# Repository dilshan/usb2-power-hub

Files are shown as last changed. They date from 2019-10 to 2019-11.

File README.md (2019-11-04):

4 Port high power USB hub 
=========================

   
  
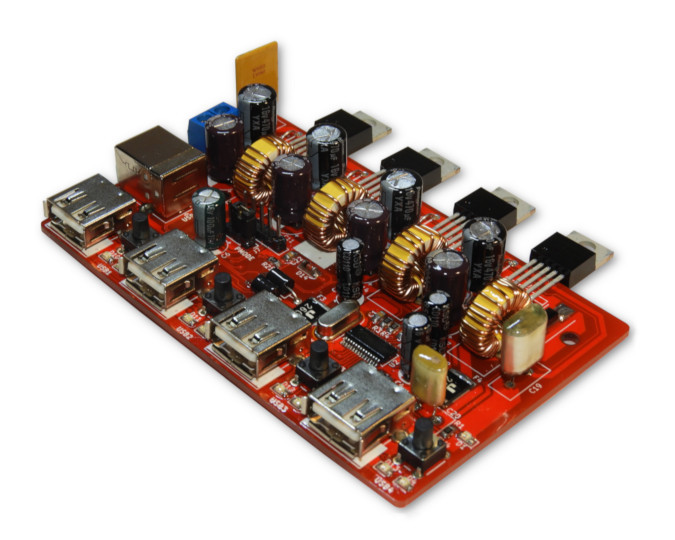
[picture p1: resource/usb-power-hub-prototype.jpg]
Prototype version of USB hub


This project is about a high current USB 2.0 hub that is specifically designed to drive USB powered development boards and experimental peripherals.

The core element of this USB hub is the *FE1.1s* USB 2.0 hub controller. The *FE1.1s* is a low cost, 4-port, high-speed USB hub controller you should be able to find on *eBay* or AliExpress.

This USB hub adds the following additional features to those offered by the *FE1.1s*:

 - Switches to on/off and reset individual USB ports.
 - Capability to provide a maximum of 3A of current from each USB port.
 - Power using 9V to 15V DC voltage source.

This USB hub uses a *PIC16F630* MCU and four *LM2596-5.0* switching regulators. 

[You can find everything about how to build and use this project on our wiki.](https://github.com/dilshan/usb2-power-hub/wiki)

Licenses
--------

This is a [certified open hardware project](https://certification.oshwa.org/lk000005.html) and all its design files, firmware source code, documentation, and other resource files are available at this project source repository. The content of this project is distributed under the terms of the following licenses:

 - Hardware License: [CC BY 4.0](https://creativecommons.org/licenses/by/4.0/)
 - Software License: [MIT](https://github.com/dilshan/usb-morse-keyer/blob/master/LICENSE)
 - Documentation License: [CC BY 4.0](https://creativecommons.org/licenses/by/4.0/)

OSHW-LK000005 (https://certification.oshwa.org/lk000005.html)

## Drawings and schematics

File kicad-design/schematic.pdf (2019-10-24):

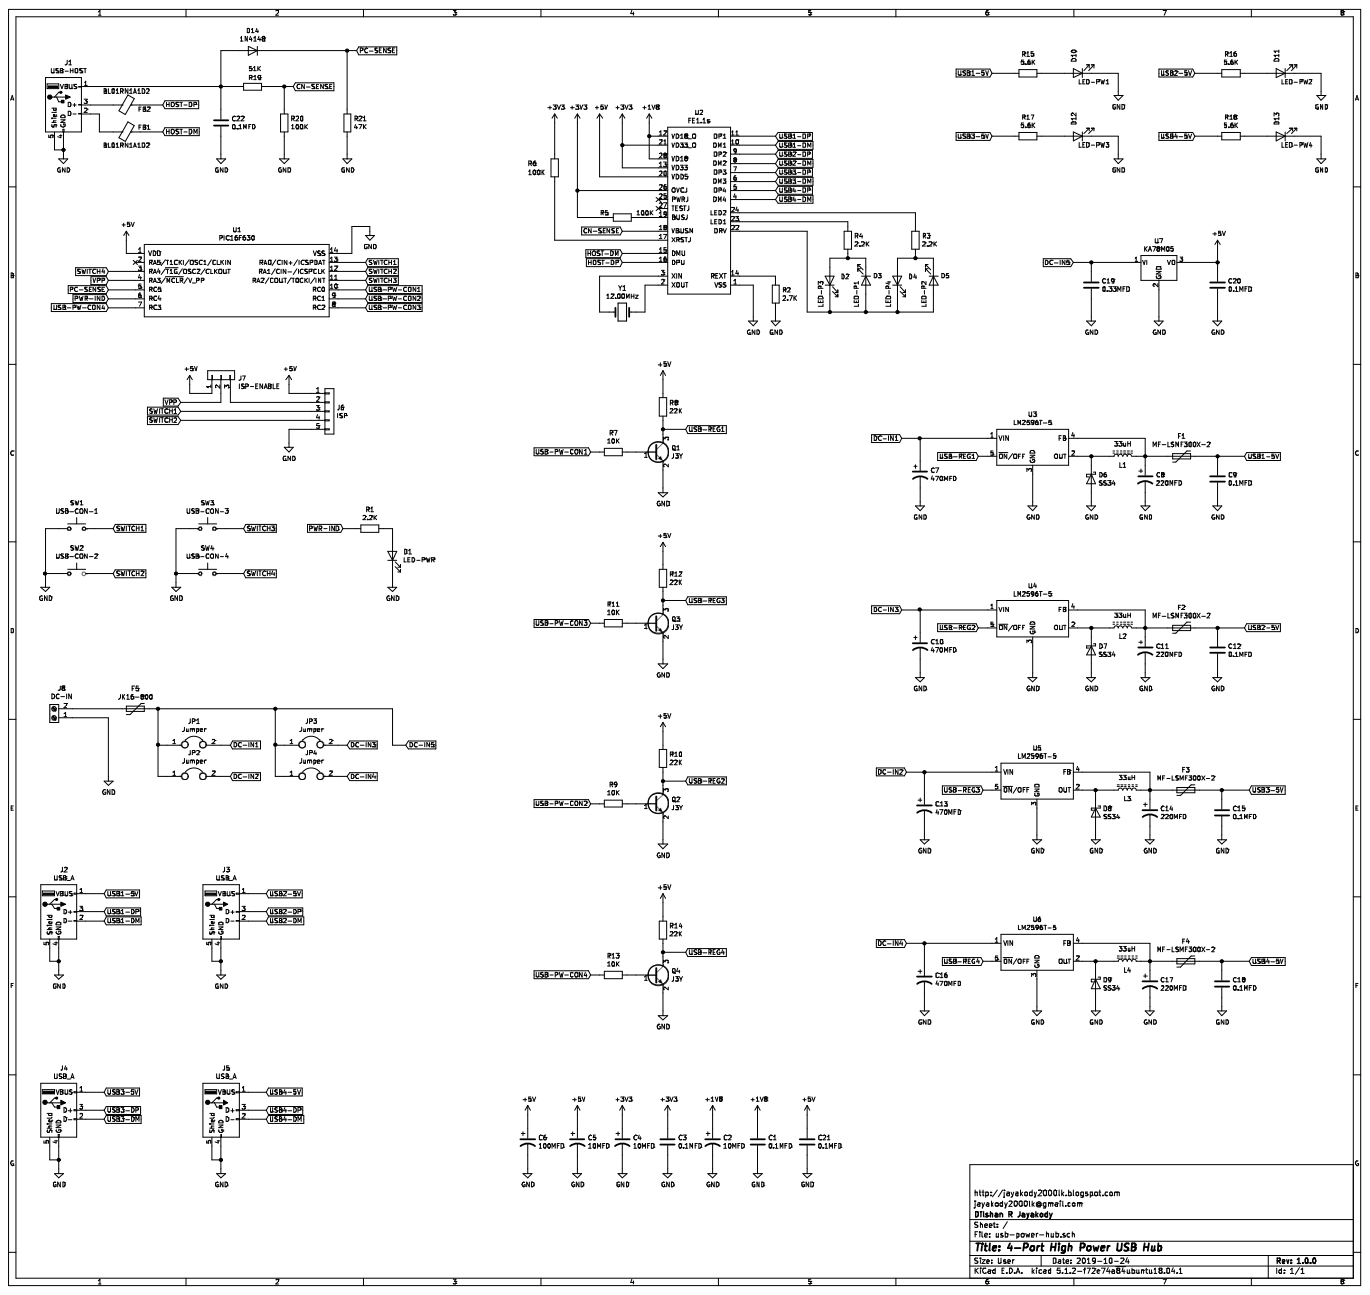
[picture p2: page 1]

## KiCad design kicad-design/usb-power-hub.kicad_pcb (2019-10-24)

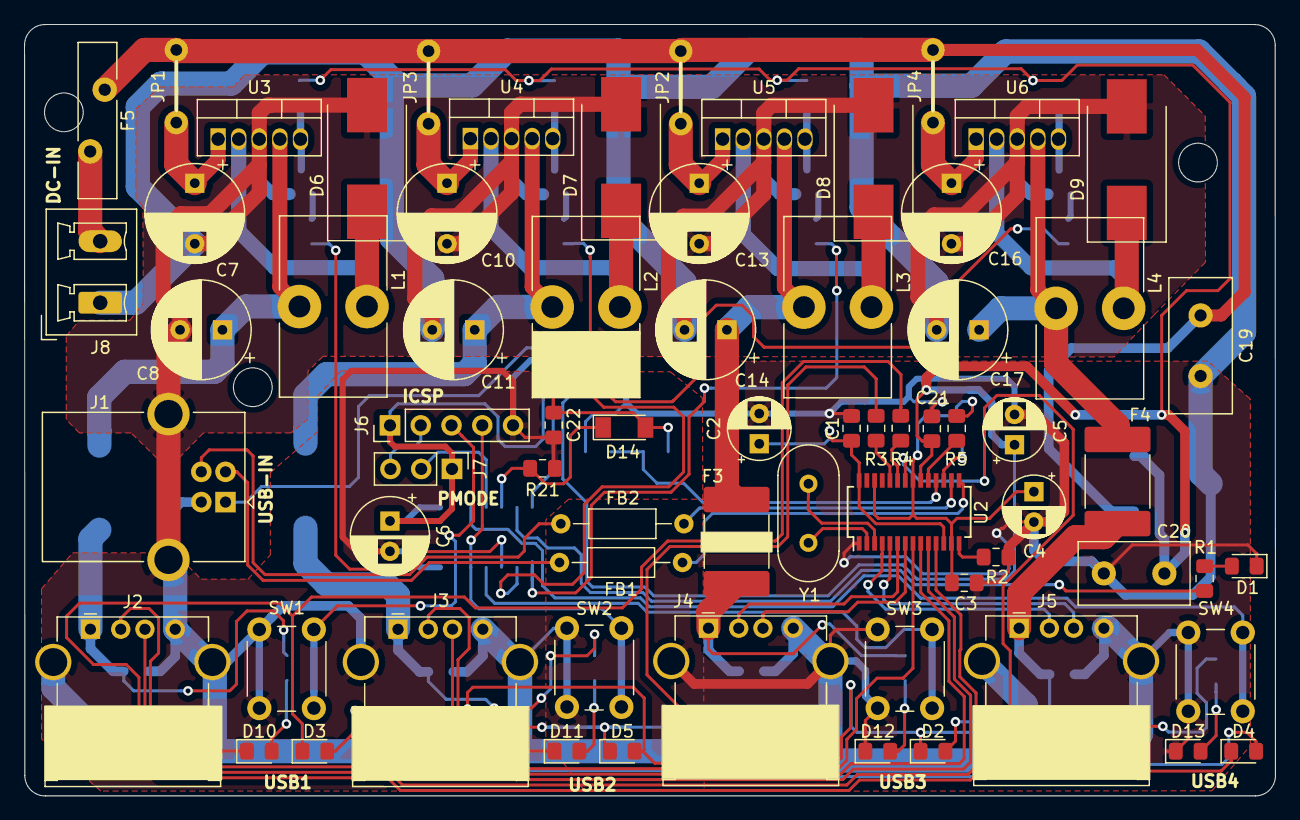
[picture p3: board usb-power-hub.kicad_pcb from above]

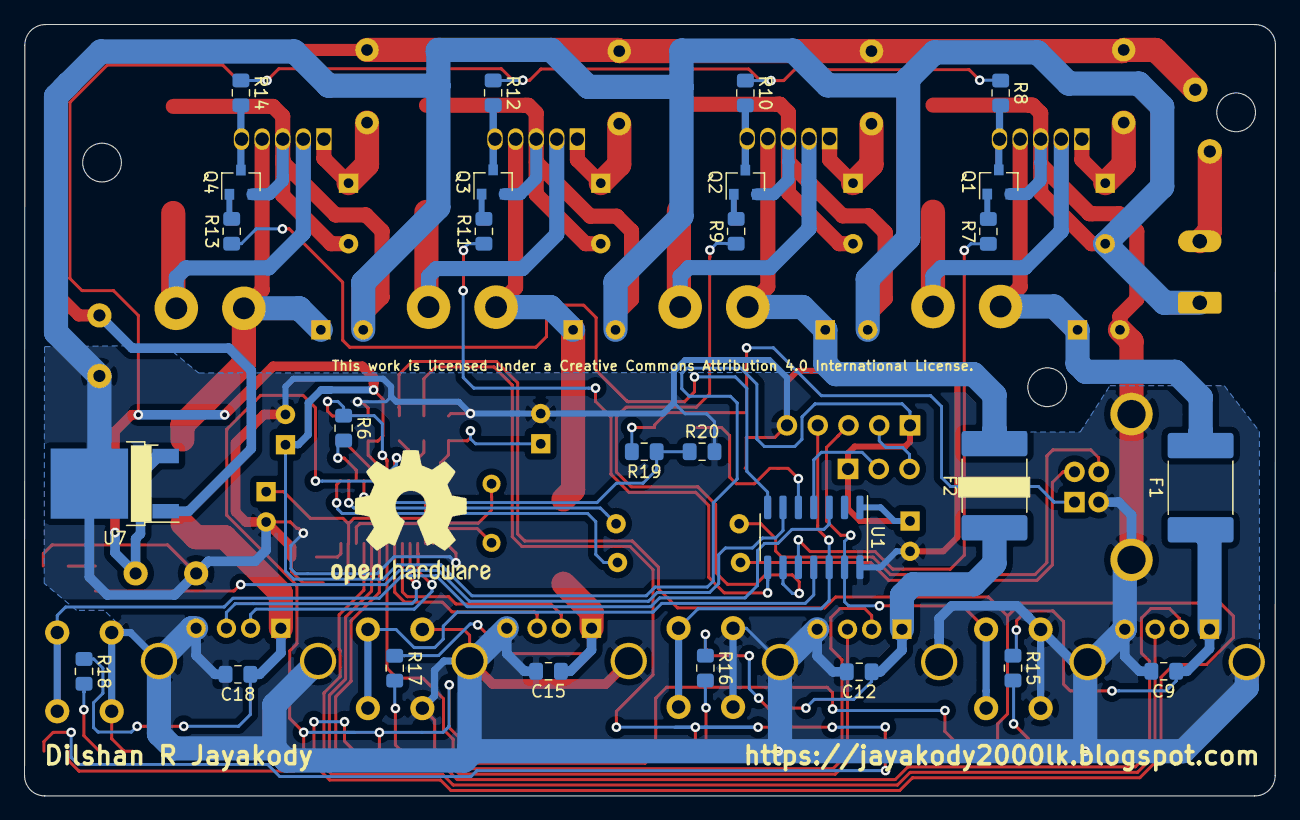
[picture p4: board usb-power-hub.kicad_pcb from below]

Board: 2 copper layers, 103.3 x 63.7 mm, 99 parts (27 on the bottom side), 71 nets.

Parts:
 : MountingHole_3.2mm_M3_ISO14580
 #2,  #3: MountingHole_3.2mm_M3_ISO14580
C1, C3, C9, C12, C15, C18, C21, C22: 0.1MFD; C_0805_2012Metric_Pad1.15x1.40mm_HandSolder
C2, C4, C5: 10MFD; CP_Radial_D5.0mm_P2.50mm
C6: 100MFD; CP_Radial_D6.3mm_P2.50mm
C7, C10, C13, C16: 470MFD; CP_Radial_D8.0mm_P5.00mm
C8, C11, C14, C17: 220MFD; CP_Radial_D8.0mm_P3.50mm
C19: 0.33MFD; C_Disc_D11.0mm_W5.0mm_P5.00mm
C20: 0.1MFD; C_Disc_D9.0mm_W5.0mm_P5.00mm
D1: LED-PWR; LED_0805_2012Metric_Pad1.15x1.40mm_HandSolder
D2: LED-P3; LED_0805_2012Metric_Pad1.15x1.40mm_HandSolder
D3: LED-P1; LED_0805_2012Metric_Pad1.15x1.40mm_HandSolder
D4: LED-P4; LED_0805_2012Metric_Pad1.15x1.40mm_HandSolder
D5: LED-P2; LED_0805_2012Metric_Pad1.15x1.40mm_HandSolder
D6, D7, D8, D9: SS34; D_SMC_Handsoldering
D10: LED-PW1; LED_0805_2012Metric_Pad1.15x1.40mm_HandSolder
D11: LED-PW2; LED_0805_2012Metric_Pad1.15x1.40mm_HandSolder
D12: LED-PW3; LED_0805_2012Metric_Pad1.15x1.40mm_HandSolder
D13: LED-PW4; LED_0805_2012Metric_Pad1.15x1.40mm_HandSolder
D14: 1N4148; D_MiniMELF
F1, F2, F3, F4: MF-LSMF300X-2; Fuse_2920_7451Metric_Pad2.10x5.45mm_HandSolder
F5: JK16-800; Fuse_Bourns_MF-RG800
FB1, FB2: BL01RN1A1D2; L_Axial_L5.3mm_D2.2mm_P10.16mm_Horizontal_Vishay_IM-1
J1: USB-HOST; USB_B_OST_USB-B1HSxx_Horizontal
J2, J3, J4, J5: USB_A; USB_A_Stewart_SS-52100-001_Horizontal
J6: ISP; PinHeader_1x05_P2.54mm_Vertical
J7: ISP-ENABLE; PinHeader_1x03_P2.54mm_Vertical
J8: DC-IN; PhoenixContact_MCV_1,5_2-G-5.08_1x02_P5.08mm_Vertical
JP1, JP2, JP3, JP4: Jumper; WireJumper
L1, L2, L3, L4: 33uH; L_Toroid_Vertical_L14.7mm_W8.6mm_P5.58mm_Pulse_KM-1
Q1, Q2, Q3, Q4: J3Y; SOT-23
R1, R3, R4: 2.2K; R_0805_2012Metric_Pad1.15x1.40mm_HandSolder
R2: 2.7K; R_0805_2012Metric_Pad1.15x1.40mm_HandSolder
R5, R6, R20: 100K; R_0805_2012Metric_Pad1.15x1.40mm_HandSolder
R7, R9, R11, R13: 10K; R_0805_2012Metric_Pad1.15x1.40mm_HandSolder
R8, R10, R12, R14: 22K; R_0805_2012Metric_Pad1.15x1.40mm_HandSolder
R15, R16, R17, R18: 5.6K; R_0805_2012Metric_Pad1.15x1.40mm_HandSolder
R19: 51K; R_0805_2012Metric_Pad1.15x1.40mm_HandSolder
R21: 47K; R_0805_2012Metric_Pad1.15x1.40mm_HandSolder
SW1: USB-CON-1; SW_PUSH_6mm
SW2: USB-CON-2; SW_PUSH_6mm
SW3: USB-CON-3; SW_PUSH_6mm
SW4: USB-CON-4; SW_PUSH_6mm
U1: PIC16F630; SOIC-14_3.9x8.7mm_P1.27mm
U2: FE1.1s; SSOP-28_3.9x9.9mm_P0.635mm
U3, U4, U5, U6: LM2596T-5; TO-220-5_Vertical
U7: KA78M05; TO-252-2
Y1: 12.00MHz; Crystal_HC49-U_Vertical

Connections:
+1V8: C1.1, C2.1, U2.12, U2.28
+3V3: C3.1, C4.1, R5.2, R6.1, U2.13, U2.21, U2.26
+5V: C5.1, C6.1, C20.1, C21.1, J6.1, J7.1, R8.1, R10.1, R12.1, R14.1, U1.1, U2.20, U7.3
CN-SENSE: R19.1, R20.1, U2.18
DC-IN1: C7.1, JP1.2, U3.1
DC-IN2: C13.1, JP2.2, U5.1
DC-IN3: C10.1, JP3.2, U4.1
DC-IN4: C16.1, JP4.2, U6.1
DC-IN5: C19.1, F5.1, JP1.1, JP2.1, JP3.1, JP4.1, U7.1
GND: C1.2, C2.2, C3.2, C4.2, C5.2, C6.2, C7.2, C8.2, C9.2, C10.2, C11.2, C12.2, C13.2, C14.2, C15.2, C16.2, C17.2, C18.2, C19.2, C20.2, C21.2, C22.2, D1.1, D6.2, D7.2, D8.2, D9.2, D10.1, D11.1, D12.1, D13.1, J1.4, J1.5, J2.4, J2.5, J3.4, J3.5, J4.4, J4.5, J5.4, J5.5, J6.5, J8.1, Q1.2, Q2.2, Q3.2, Q4.2, R2.2, R20.2, R21.2, SW1.1, SW2.1, SW3.1, SW4.1, U1.14, U2.1, U3.3, U4.3, U5.3, U6.3, U7.2
HOST-DM: FB1.1, U2.15
HOST-DP: FB2.1, U2.16
unnamed: C8.1, F1.2, L1.2, U3.4
unnamed: C11.1, F2.2, L2.2, U4.4
unnamed: C14.1, F3.2, L3.2, U5.4
unnamed: C17.1, F4.2, L4.2, U6.4
unnamed: C22.1, D14.2, J1.1, R19.2
unnamed: D1.2, R1.2
unnamed: D2.1, D3.2, D4.1, D5.2, U2.22
unnamed: D2.2, D3.1, R4.2
unnamed: D4.2, D5.1, R3.2
unnamed: D6.1, L1.1, U3.2
unnamed: D7.1, L2.1, U4.2
unnamed: D8.1, L3.1, U5.2
unnamed: D9.1, L4.1, U6.2
unnamed: D10.2, R15.2
unnamed: D11.2, R16.2
unnamed: D12.2, R17.2
unnamed: D13.2, R18.2
unnamed: F5.2, J8.2
unnamed: FB1.2, J1.2
unnamed: FB2.2, J1.3
unnamed: J6.2, J7.3
unnamed: Q1.1, R7.2
unnamed: Q2.1, R9.2
unnamed: Q3.1, R11.2
unnamed: Q4.1, R13.2
unnamed: R2.1, U2.14
unnamed: R3.1, U2.24
unnamed: R4.1, U2.23
unnamed: R5.1, U2.19
unnamed: R6.2, U2.17
unnamed: U2.2, Y1.2
unnamed: U2.3, Y1.1
PC-SENSE: D14.1, R21.1, U1.5
PWR-IND: R1.1, U1.6
SWITCH1: J6.3, SW1.2, U1.13
SWITCH2: J6.4, SW2.2, U1.12
SWITCH3: SW3.2, U1.11
SWITCH4: SW4.2, U1.3
USB1-5V: C9.1, F1.1, J2.1, R15.1
USB1-DM: J2.2, U2.10
USB1-DP: J2.3, U2.11
USB2-5V: C12.1, F2.1, J3.1, R16.1
USB2-DM: J3.2, U2.8
USB2-DP: J3.3, U2.9
USB3-5V: C15.1, F3.1, J4.1, R17.1
USB3-DM: J4.2, U2.6
USB3-DP: J4.3, U2.7
USB4-5V: C18.1, F4.1, J5.1, R18.1
USB4-DM: J5.2, U2.4
USB4-DP: J5.3, U2.5
USB-PW-CON1: R7.1, U1.10
USB-PW-CON2: R9.1, U1.9
USB-PW-CON3: R11.1, U1.8
USB-PW-CON4: R13.1, U1.7
USB-REG1: Q1.3, R8.2, U3.5
USB-REG2: Q2.3, R10.2, U4.5
USB-REG3: Q3.3, R12.2, U5.5
USB-REG4: Q4.3, R14.2, U6.5
VPP: J7.2, U1.4

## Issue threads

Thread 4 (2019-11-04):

Standalone USB Device Charger feature?

rayrrr, 2019-11-04:
Thanks for the cool project! Can this device also act as a standalone USB Device Charger when powered via 12-20V but not connected to a host computer via USB?

In other words, can I charge my phone with it?

If so, let's document that in the Usage Instructions in the wiki.

dilshan, 2019-11-05:
@rayrrr With current firmware this hub need to connect with host computer to activate it's 4 ports. If you are interested to use this as a USB device charger you need to modify "_USB sense_" section of the firmware.

As you suggested I'll add this feature request to my next firmware update.

dgags, 2021-09-11:
To turn this into a charging only device, it looks like you can change line 35 in "usb2-power-hub/firmware/main.c"
from:  usbFlag = PORTC & 0x20;
to:       usbFlag = 0x20;

If I have this right, it should basically just say that the USB host is always connected without bothering to really look if it connected to a computer. I admit that this does not elegantly solve the problem in a way that allows you to selectively turn this feature on and off. I would expect a hardwired switch that the PIC could query is one such way.

I hope this helps anyone wanting to turn this into a high current multi-port usb charging device.

dilshan, 2021-09-12:
@dgags good suggestion!
Yes, assigning `0x20` to the `usbFlag`, disable the USB sense feature from the firmware. I did not include this in firmware because this may change the scope of the project (from USB hub to USB charger).

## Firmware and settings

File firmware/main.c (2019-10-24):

//***********************************************************************************
// Copyright (c) 2019 Dilshan R Jayakody. [jayakody2000lk@gmail.com]
//
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
#include <xc.h>

#include "main.h"

int main() 
{
    unsigned char idleCounter = 0;
    unsigned char idleFlag = 0;
    
    initSystem();
    
    while(1)
    {
        usbFlag = PORTC & 0x20;
                
        if(usbFlag == 0x20)
        {
            // USB host connection is triggered and start to verify the connection.

            PORTC = 0x00;
            __delay_ms(500);
            usbFlag = PORTC & 0x20;
            
            if(usbFlag == 0x20)
            {
                // USB host connection is available and turn on the USB HUB.

                switchConfig = eeprom_read(0x00);
                liveServiceRoutine();
                
                // Host USB line is disconnected. Shutting down all USB ports.
                idleCounter = 0;
                idleFlag = 0;
                PORTC = 0x00;
            }
        }
        else 
        {
            // Blink power indicator in USB disconnected mode. 
            if((++idleCounter) == 10)
            {
                idleFlag = ~idleFlag;
                
                if(idleFlag == 0)
                {
                    PORTC = 0x00;
                    idleCounter = 0;
                }
                else
                {
                    PORTC = 0x10;
                    idleCounter = 8;
                }
            }
        }
        
        __delay_ms(100);
    }
}

void toggleStateBit(unsigned char togglePos, unsigned char *globalConfig, unsigned char *localConfig)
{
    if(((*globalConfig) & togglePos) == 0x00)
    {
        // Activate the specified bit.
        (*globalConfig) |= togglePos;
        (*localConfig) |= togglePos;
    }
    else
    {
        // Clear the specified bit.
        (*globalConfig) &= (~togglePos);
        (*localConfig) &= (~togglePos);
    }
}

void liveServiceRoutine()
{
    unsigned char buttonState = PORTA;
    unsigned char lastButtonState = buttonState;
    
    unsigned char resetState[4] = {0x00, 0x00, 0x00, 0x00};
    unsigned char buttonDownCounter[4] = {0x00, 0x00, 0x00, 0x00};
    
    // Restore USB ports to last state.
    switchConfig |= 0x10;
    unsigned char memSwitchConfig = switchConfig;
    
    while(usbFlag == 0x20)
    {
        PORTC = switchConfig;

        // Initiate reset cycle for USB port #1.  
        if(BUTTON_PRESSED(BUTTON_1) && ((memSwitchConfig & USB_PORT_1) == USB_PORT_1))
        {
            resetState[0] = RESET_LIMIT;
            switchConfig &= (~USB_PORT_1);
            buttonDownCounter[0] = 0;
        }
        
        // Initiate reset cycle for USB port #2.
        if(BUTTON_PRESSED(BUTTON_2) && ((memSwitchConfig & USB_PORT_2) == USB_PORT_2))
        {
            resetState[1] = RESET_LIMIT;
            switchConfig &= (~USB_PORT_2);
            buttonDownCounter[1] = 0;
        }
        
        // Initiate reset cycle for USB port #3.
        if(BUTTON_PRESSED(BUTTON_3) && ((memSwitchConfig & USB_PORT_3) == USB_PORT_3))
        {
            resetState[2] = RESET_LIMIT;
            switchConfig &= (~USB_PORT_3);
            buttonDownCounter[2] = 0;
        }
        
        // Initiate reset cycle for USB port #4.
        if(BUTTON_PRESSED(BUTTON_4) && ((memSwitchConfig & USB_PORT_4) == USB_PORT_4))    
        {
            resetState[3] = RESET_LIMIT;
            switchConfig &= (~USB_PORT_4);
            buttonDownCounter[3] = 0;
        }
        
        // Button #1 hold down counter to detect long presses.
        if(IS_BUTTON_DOWN(BUTTON_1, 0))
        {
            buttonDownCounter[0]++;
        }
        
        // Button #2 hold down counter to detect long presses.
        if(IS_BUTTON_DOWN(BUTTON_2, 1))
        {
            buttonDownCounter[1]++;
        }
        
        // Button #3 hold down counter to detect long presses.
        if(IS_BUTTON_DOWN(BUTTON_3, 2))
        {
            buttonDownCounter[2]++;
        }
        
        // Button #4 hold down counter to detect long presses.
        if(IS_BUTTON_DOWN(BUTTON_4, 3))
        {
            buttonDownCounter[3]++;
        }
        
        // Check reset timeout for each USB port, and restore port power. 
        if((resetState[0] | resetState[1] | resetState[2] | resetState[3]) != 0)
        {
            resetState[0] -= (resetState[0] != 0) ? 1 : 0;
            resetState[1] -= (resetState[1] != 0) ? 1 : 0;
            resetState[2] -= (resetState[2] != 0) ? 1 : 0;
            resetState[3] -= (resetState[3] != 0) ? 1 : 0;
            
            if(IS_PORT_ACTIVE(USB_PORT_1))
            {
                switchConfig |= (resetState[0] < 2) ? USB_PORT_1 : 0x00;
            }
            
            if(IS_PORT_ACTIVE(USB_PORT_2))
            {
                switchConfig |= (resetState[1] < 2) ? USB_PORT_2 : 0x00;
            }
            
            if(IS_PORT_ACTIVE(USB_PORT_3))
            {
                switchConfig |= (resetState[2] < 2) ? USB_PORT_3 : 0x00;
            }
            
            if(IS_PORT_ACTIVE(USB_PORT_4))
            {
                switchConfig |= (resetState[3] < 2) ? USB_PORT_4 : 0x00;
            }
        }
        
        // Long press handler to shutdown/activate USB port #1.
        if(buttonDownCounter[0] >= BUTTON_DOWN_TIME)
        {
            toggleStateBit(USB_PORT_1, &memSwitchConfig, &switchConfig);
            
            PORTC = switchConfig;
            eeprom_write(0x00, memSwitchConfig);
            
            while((buttonState & BUTTON_1) == 0x00)
            {
                __delay_ms(100);
                buttonState = PORTA;
            }
            
            buttonDownCounter[0] = 0;
        }
        
        // Long press handler to shutdown/activate USB port #2.
        if(buttonDownCounter[1] >= BUTTON_DOWN_TIME)
        {
            toggleStateBit(USB_PORT_2, &memSwitchConfig, &switchConfig);
            
            PORTC = switchConfig;
            eeprom_write(0x00, memSwitchConfig);
            
            while((buttonState & BUTTON_2) == 0x00)
            {
                __delay_ms(100);
                buttonState = PORTA;
            }
            
            buttonDownCounter[1] = 0;
        }
        
        // Long press handler to shutdown/activate USB port #3.
        if(buttonDownCounter[2] >= BUTTON_DOWN_TIME)
        {
            toggleStateBit(USB_PORT_3, &memSwitchConfig, &switchConfig);
            
            PORTC = switchConfig;
            eeprom_write(0x00, memSwitchConfig);
            
            while((buttonState & BUTTON_3) == 0x00)
            {
                __delay_ms(100);
                buttonState = PORTA;
            }
            
            buttonDownCounter[2] = 0;
        }
        
        // Long press handler to shutdown/activate USB port #4.
        if(buttonDownCounter[3] >= BUTTON_DOWN_TIME)
        {
            toggleStateBit(USB_PORT_4, &memSwitchConfig, &switchConfig);
            
            PORTC = switchConfig;
            eeprom_write(0x00, memSwitchConfig);
            
            while((buttonState & BUTTON_4) == 0x00)
            {
                __delay_ms(100);
                buttonState = PORTA;
            }
            
            buttonDownCounter[3] = 0;
        }
        
        lastButtonState = buttonState;
        __delay_ms(100);
        
        buttonState = PORTA;
        usbFlag = PORTC & 0x20;
    }
}

void initSystem()
{
    // Initialize MCU peripherals to known state.
    OPTION_REG = 0x00;
    CMCON = 0x07;
    
    TRISC = 0xE0;
    PORTC = 0x00;
    
    TRISA = 0xFF;
    PORTA = 0x00;
    WPUA = 0xFF;
    
    // Initialize all global variables to known state.
    powerControlStatus = PORTC;
    usbFlag = PORTC & 0x20;
    switchConfig = 0x0F;
}

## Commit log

2019-10-24 Initial version of design files.
    [usb-power-hub.kicad_pcb, usb-power-hub.sch]
2019-10-24 Add image of the prototype hub.

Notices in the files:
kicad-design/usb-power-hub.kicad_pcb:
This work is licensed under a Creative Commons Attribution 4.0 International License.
